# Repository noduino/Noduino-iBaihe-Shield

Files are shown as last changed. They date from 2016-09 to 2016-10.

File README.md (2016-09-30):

Noduino iBaihe Board
=======================================

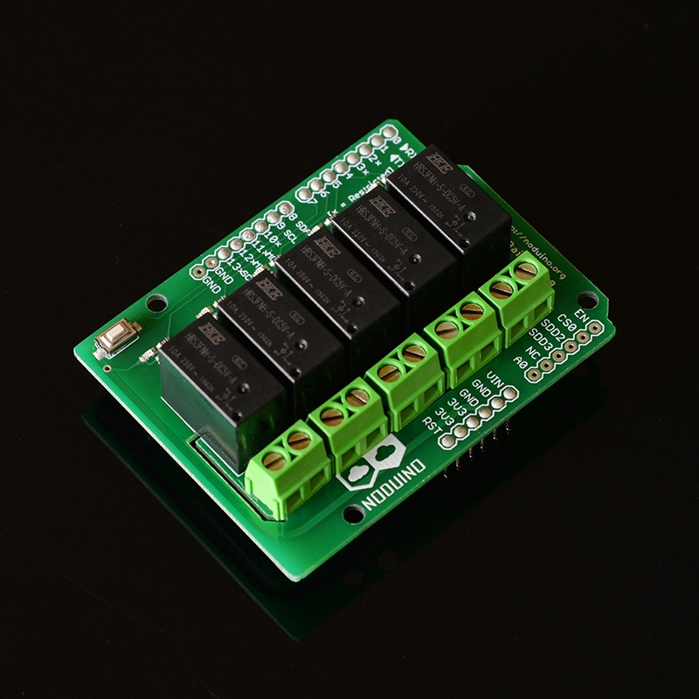
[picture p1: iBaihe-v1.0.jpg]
Noduino iBaihe Board V1.0


[*Noduino iBaihe Board - Complete iBaihe board (iBaihe V1.0)*](https://www.noduino.org/)

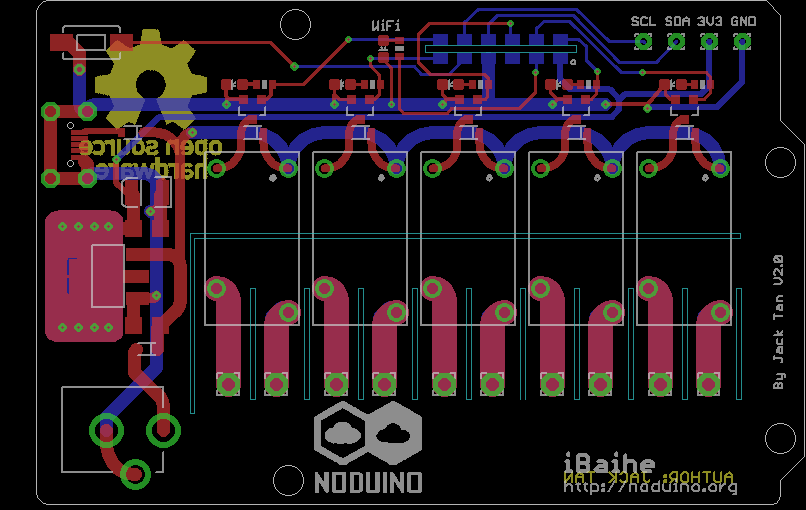
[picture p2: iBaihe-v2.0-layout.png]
Noduino iBaihe Board V2.0


[*Noduino iBaihe Board Bottom - Complete iBaihe board*](https://www.noduino.org/)

Overview
-------------------
There are 5 Relays in the iBaihe board. It's designed for home automation.

iBaihe V2.0 is a 5 relays Standalone version that use a NodeC module (a coin-sized ESP8285 module).

iBaihe V1.0 is a arduino-compatible 5 relays shield.

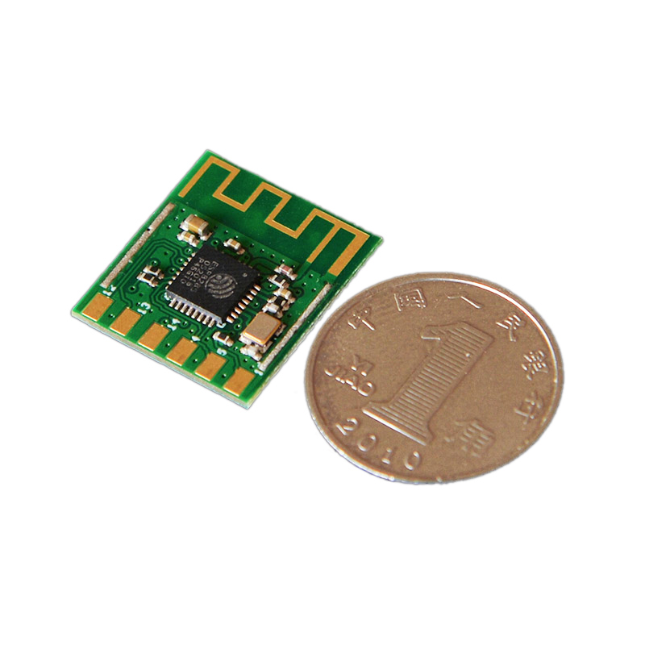
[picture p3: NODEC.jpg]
NodeC


[*Noduino NodeC WiFi Module*](https://www.noduino.org/products/nodec)

The pin map of iBaihe v2.0 Board:

* D3	(GPIO15)  ---> control the 5th relay

* D4	(GPIO13)  ---> control the 1st relay
* D5	(GPIO12)  ---> control the 2nd relay
* D6	(GPIO14)  ---> control the 3rd relay
* D7	(GPIO16)  ---> control the 4th relay

* D8	(GPIO4)   ---> as i2c SDA
* D9	(GPIO5)   ---> as i2c SCL

* D10	(GPIO0)   ---> input key
* D0	(GPIO3)   ---> WiFI Status LED

The pin map of iBaihe v1.0 shield board:

* D4	(GPIO13)  ---> control the 1st relay
* D5	(GPIO12)  ---> control the 2nd relay
* D6	(GPIO14)  ---> control the 3rd relay
* D7	(GPIO16)  ---> control the 4th relay

* D8	(GPIO4)   ---> control the 5th relay

* D10	(GPIO0)   ---> input key

Repository Contents
-------------------
* V2.0/ - All Eagle desgin files (.brd, .sch) and Gerber files of iBaihe v2.0
* V1.0/ - All Eagle design files (.brd, .sch) and Gerber files of iBaihe v1.0 shield

Product Versions
----------------
* [FALCON-100](http://www.noduino.org/) - As a 5 relays shield for Falcon/Quantum board.
* [FALCON-200](http://www.noduino.org/) - 5 relays Standalone version using a NodeC module (Our coin-sized ESP8285 module).

License Information
-------------------
The hardware is released under [Creative Commons ShareAlike 4.0 International](https://creativecommons.org/licenses/by-sa/4.0/).

Distributed as-is; no warranty is given.

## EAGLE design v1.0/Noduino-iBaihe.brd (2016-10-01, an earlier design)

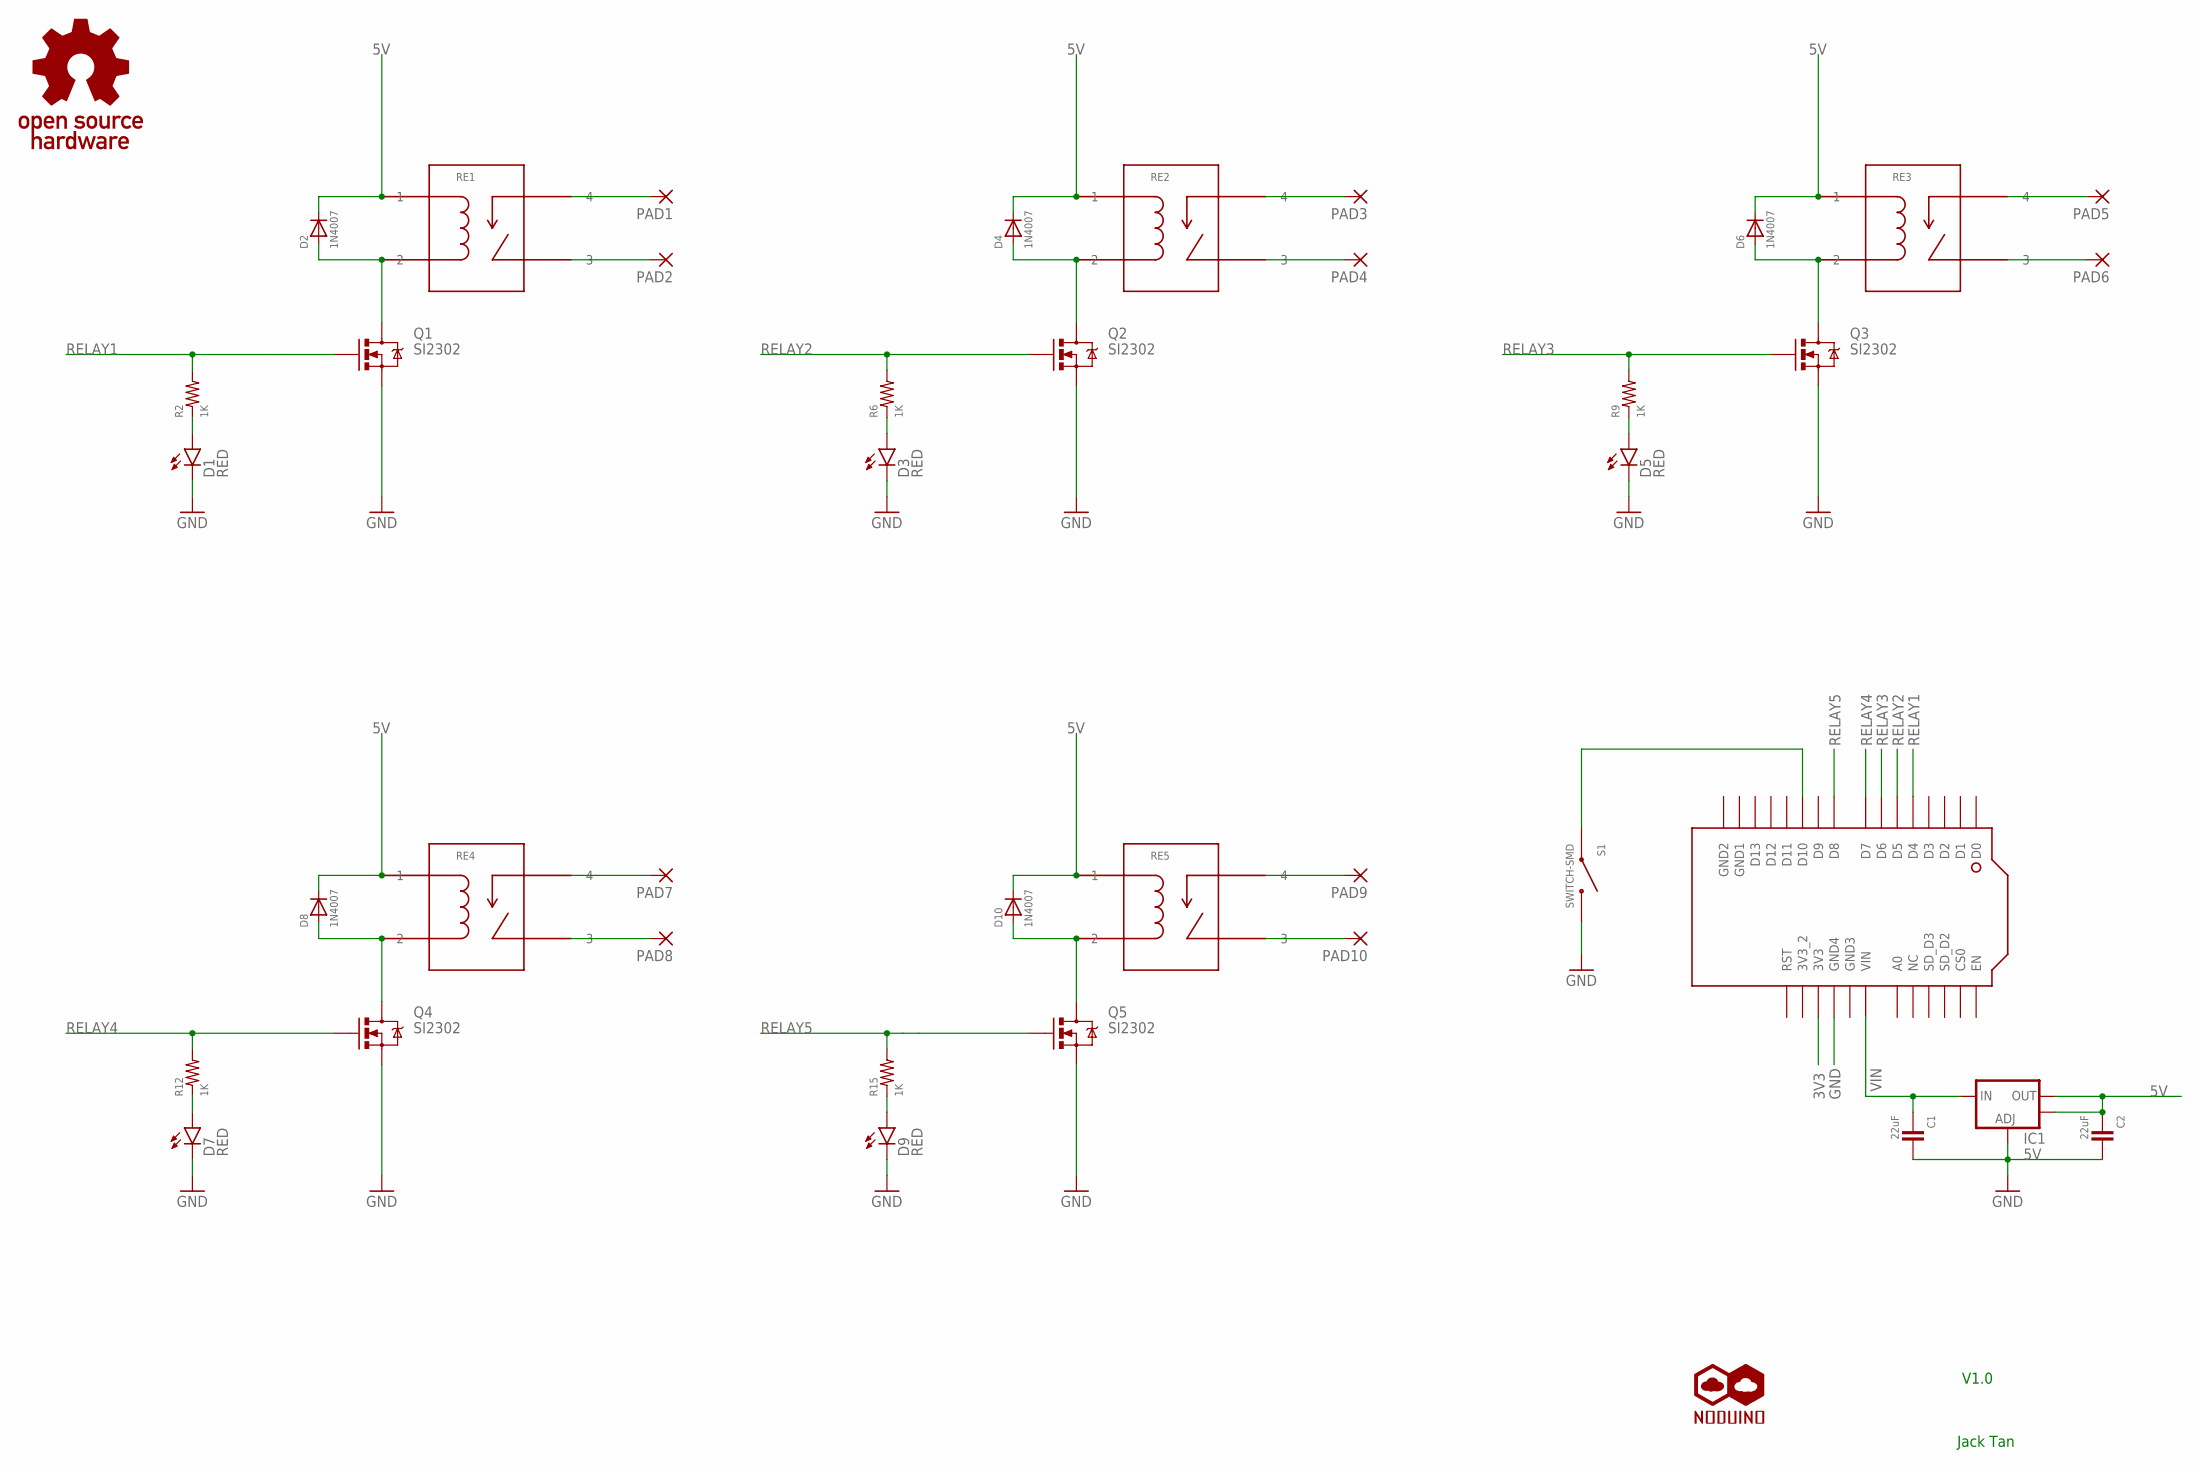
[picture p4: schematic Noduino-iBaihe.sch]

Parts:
C1, C2: 22uF; C1206
D1, D3, D5, D7, D9: RED; LED-0603
D2, D4, D6, D8, D10: 1N4007; SOD-323
IC1: 5V; SOT223
N1: NODUINO-PINMAIL; NODUINO-PIN-MAIL
PAD1, PAD2, PAD3, PAD4, PAD5, PAD6, PAD7, PAD8, PAD9, PAD10: 2,15/1,0
Q1, Q2, Q3, Q4, Q5: SI2302; SOT23-3
R2, R6, R9, R12, R15: 1K; 0603-RES
RE1, RE2, RE3, RE4, RE5: HKE-HRS3FNH; HKE-HRS3FN
S1: SWITCH-SMD; TACTILE-SWITCH-1101NE
U$1: NODUINO-LOGO-ALL; NODUINO-ALL-1
U$2: OPEN_HARDWARE_LOGO

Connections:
3V3: N1.P$26 (3V3)
5V: C2.1, D2.1 (C), D4.1 (C), D6.1 (C), D8.1 (C), D10.1 (C), IC1.2 (OUT), IC1.4 (OUT), RE1.1, RE2.1, RE3.1, RE4.1, RE5.1
GND: C1.2, C2.2, D1.C, D3.C, D5.C, D7.C, D9.C, IC1.1 (ADJ), N1.P$25 (GND4), Q1.2 (S), Q2.2 (S), Q3.2 (S), Q4.2 (S), Q5.2 (S), S1.P$1 (1)
unnamed: D2.2 (A), Q1.3 (D), RE1.2
unnamed: PAD1.1, RE1.4
unnamed: D1.A, R2.1
unnamed: PAD2.1, RE1.3
unnamed: D3.A, R6.1
unnamed: D4.2 (A), Q2.3 (D), RE2.2
unnamed: PAD3.1, RE2.4
unnamed: PAD4.1, RE2.3
unnamed: D5.A, R9.1
unnamed: D6.2 (A), Q3.3 (D), RE3.2
unnamed: PAD5.1, RE3.4
unnamed: PAD6.1, RE3.3
unnamed: D7.A, R12.1
unnamed: D8.2 (A), Q4.3 (D), RE4.2
unnamed: PAD7.1, RE4.4
unnamed: PAD8.1, RE4.3
unnamed: D9.A, R15.1
unnamed: D10.2 (A), Q5.3 (D), RE5.2
unnamed: PAD9.1, RE5.4
unnamed: PAD10.1, RE5.3
unnamed: N1.P$11 (D10), S1.P$2 (2)
RELAY1: N1.P$5 (D4), Q1.1 (G), R2.2
RELAY2: N1.P$6 (D5), Q2.1 (G), R6.2
RELAY3: N1.P$7 (D6), Q3.1 (G), R9.2
RELAY4: N1.P$8 (D7), Q4.1 (G), R12.2
RELAY5: N1.P$9 (D8), Q5.1 (G), R15.2
VIN: C1.1, IC1.3 (IN), N1.P$23 (VIN)

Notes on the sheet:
Jack Tan
V1.0

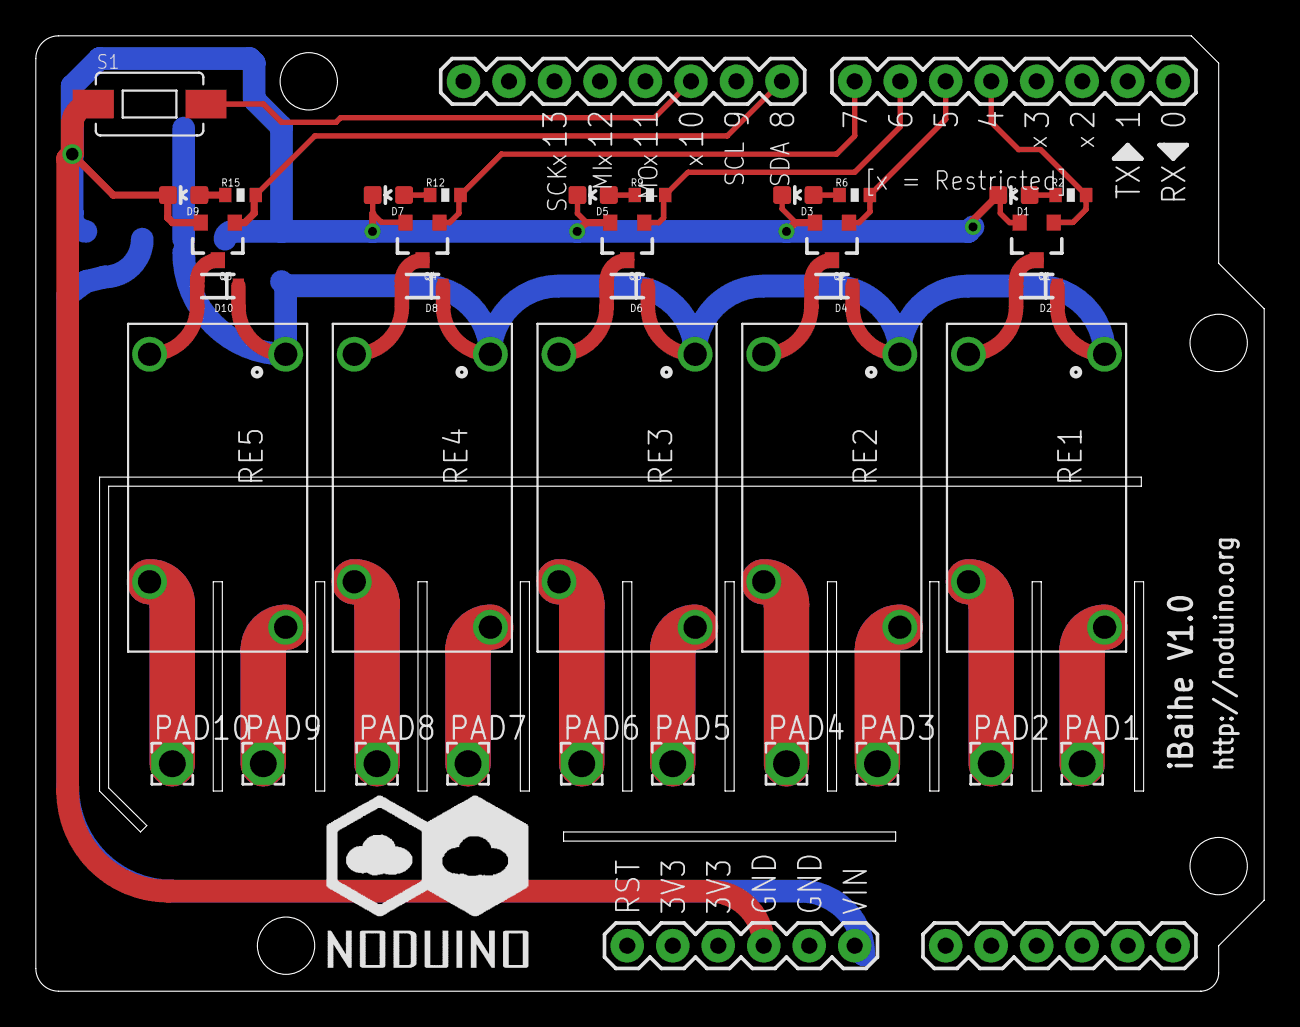
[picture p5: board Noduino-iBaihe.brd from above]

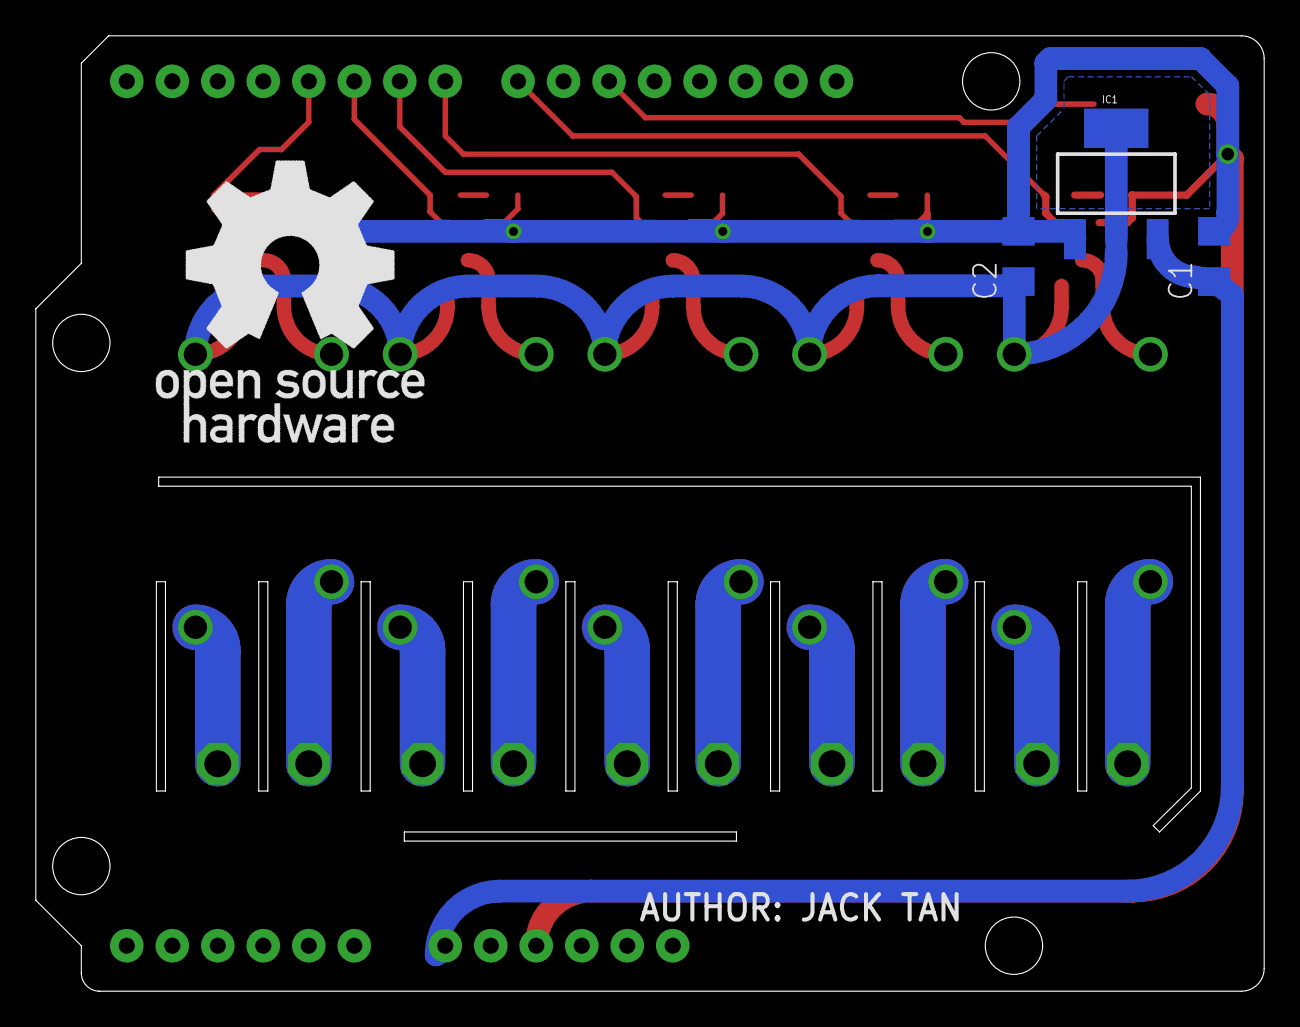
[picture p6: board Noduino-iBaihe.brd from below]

Board: 2 copper layers, 68.6 x 53.3 mm, 42 parts (4 on the bottom side), 29 nets.

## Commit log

2016-09-30 add the ibaihe v2.0 sch and layout files
    eagle format
    [Noduino-iBaihe.brd, Noduino-iBaihe.sch]
2016-09-30 add the ibaihe version 1.0 eagle designed files
    [Noduino-iBaihe.brd, Noduino-iBaihe.sch]
2016-09-30 add the readme and board images
2016-09-30 add the board image of ibaihe v1.0
2016-10-01 change the drill size of pins interface to 0.9mm
    The old drill size of v1.0 shield is 0.7mm.
    It's too small
    [Noduino-iBaihe.brd, Noduino-iBaihe.sch]
